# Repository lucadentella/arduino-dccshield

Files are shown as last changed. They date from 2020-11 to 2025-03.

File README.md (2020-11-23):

# DCCShield for Arduino

Optocoupled interface to connect Arduino to the DCC bus.

Available both as an Arduino shield and as a standalone board.

*Interfaccia optoisolata per collegare Arduino al bus DCC.*

*Disponibile sia come shield Arduino che come scheda autonoma.*

## Firmware

In the Arduino folder, a basic sketch is available to implement a DCC decoder as explained in the video.

*Nella cartella Arduino, è disponibile un semplice sketch per implementare un decoder DCC come illustrato nel video.*

## Documentation

 - [Tutorial in **English**](https://youtu.be/aA6cgGWZWBE) (Youtube)
 - [Tutorial in **Italiano**](https://youtu.be/_3cTWvrFvNA) (Youtube)

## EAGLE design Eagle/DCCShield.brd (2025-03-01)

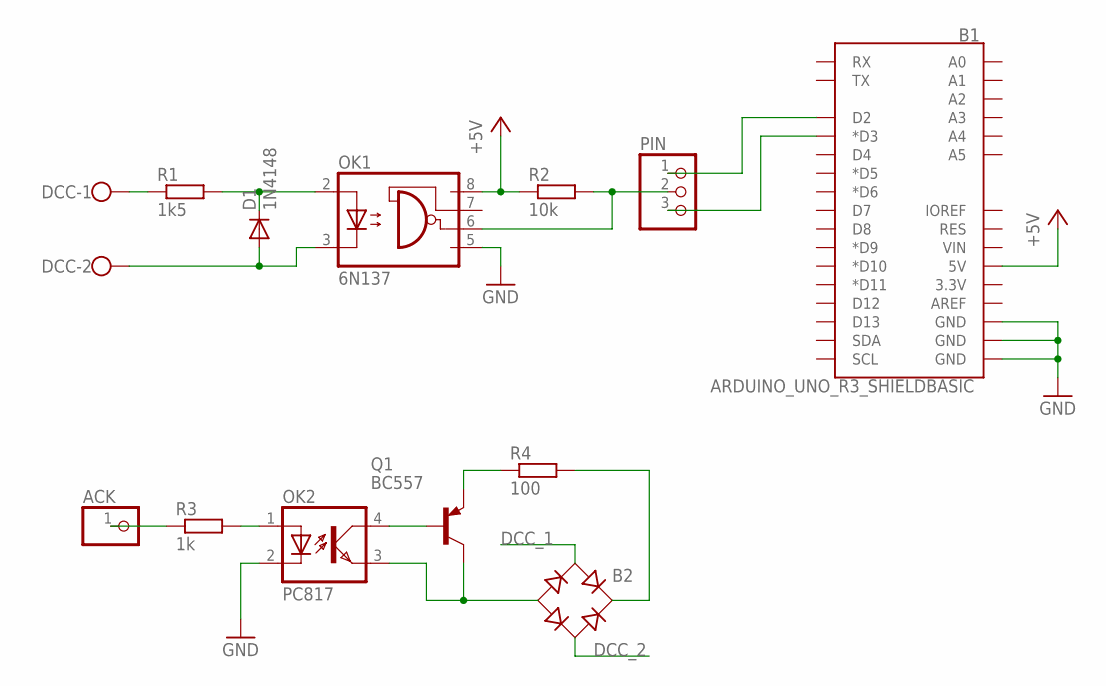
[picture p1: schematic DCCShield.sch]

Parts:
ACK: PINHD-1X1; 1X01
B1: ARDUINO_UNO_R3_SHIELDBASIC; UNO_R3_SHIELD
B2: RB1A
D1: 1N4148; DO35-10
DCC: W237-102
OK1: 6N137; DIL08
OK2: PC817; DIL04
PIN: PINHD-1X3; 1X03
Q1: BC557; TO92
R1: 1k5; 0207/10
R2: 10k; 0207/10
R3: 1k; 0207/10
R4: 100; 0207/10

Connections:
+5V: B1.5V, OK1.8 (VCC), R2.1
DCC_1: B2.AC1, DCC.1, R1.1
DCC_2: B2.AC2, D1.A, DCC.2, OK1.3 (C)
GND: B1.GND@0 (GND), B1.GND@1 (GND), B1.GND@2 (GND), OK1.5 (GND), OK2.2 (C)
unnamed: B2.-, OK2.3 (EMIT), Q1.3 (C)
unnamed: D1.C, OK1.2 (A), R1.2
unnamed: ACK.1, R3.1
unnamed: OK1.6 (VO), PIN.2, R2.2
unnamed: B1.D2, PIN.1
unnamed: B1.D3 (*D3), PIN.3
unnamed: OK2.1 (A), R3.2
unnamed: OK2.4 (COL), Q1.2 (B)
unnamed: Q1.1 (E), R4.1
unnamed: B2.+, R4.2

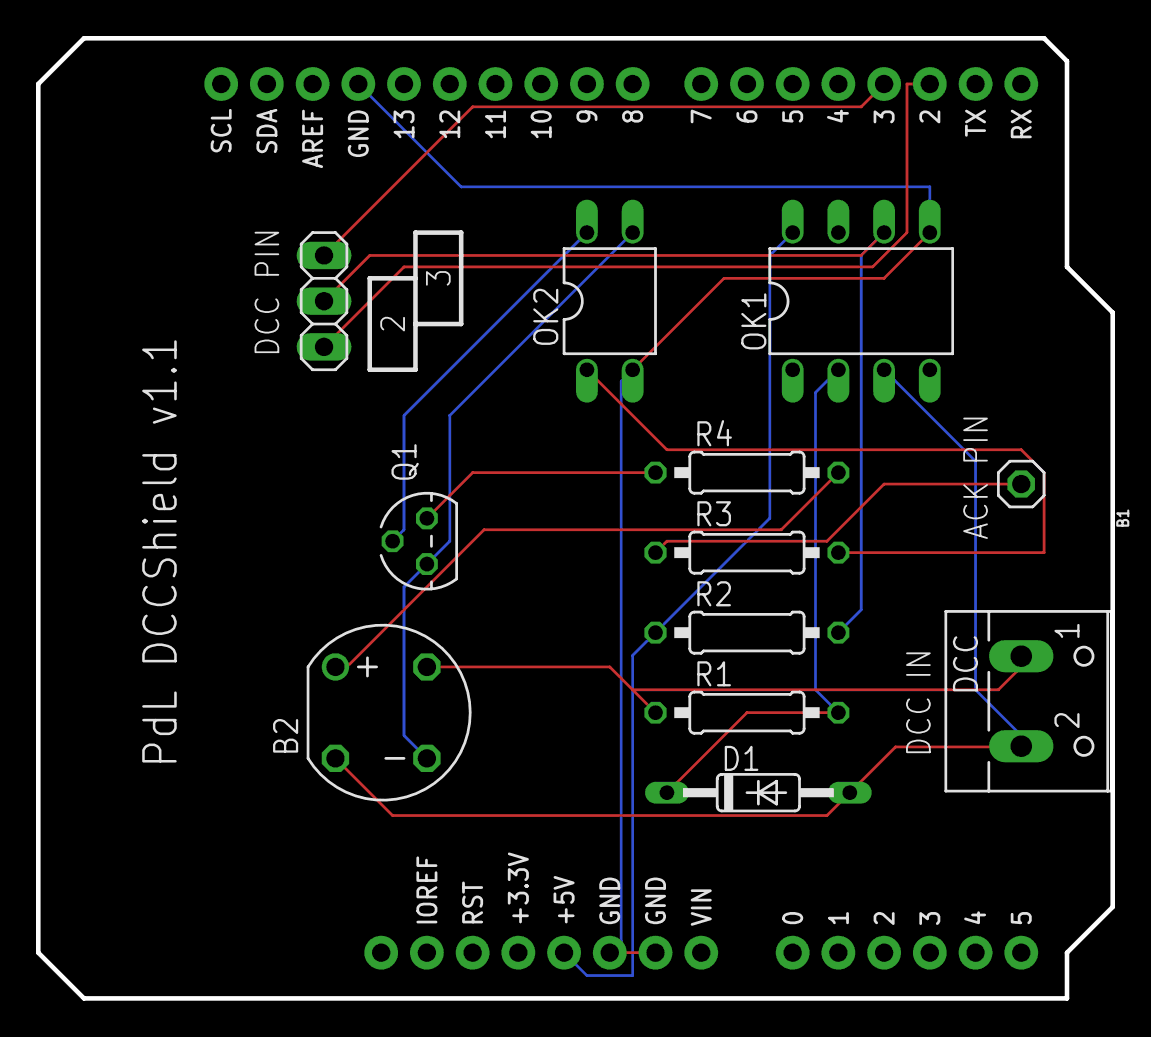
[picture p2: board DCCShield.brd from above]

Board: 2 copper layers, 59.7 x 53.3 mm, 13 parts (0 on the bottom side), 14 nets.

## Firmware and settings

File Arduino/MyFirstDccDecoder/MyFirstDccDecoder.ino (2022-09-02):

#include <NmraDcc.h>

#define DCC_PIN 2
#define ACK_PIN 3
#define RED_LED 4
#define GREEN_LED 5

#define DECODER_ADDR 4

NmraDcc Dcc;

void notifyDccAccTurnoutOutput(uint16_t Addr, uint8_t Direction, uint8_t OutputPower) {

  if(Addr == DECODER_ADDR) {
    if(Direction == 0) {
      digitalWrite(RED_LED, HIGH);
      digitalWrite(GREEN_LED, LOW);
    } else {
      digitalWrite(RED_LED, LOW);
      digitalWrite(GREEN_LED, HIGH);    
    }
  }
    
  Serial.print("Address: "); Serial.println(Addr);
  Serial.print("Direction: "); Serial.println(Direction);
  Serial.print("OutputPower: "); Serial.println(OutputPower);
  Serial.println("--------------------");
}

void notifyCVAck(void) {

  digitalWrite(ACK_PIN, HIGH);
  delay(10);  
  digitalWrite(ACK_PIN, LOW);
}

void setup() {

  Serial.begin(115200);
  pinMode(ACK_PIN, OUTPUT);
  pinMode(RED_LED, OUTPUT);
  pinMode(GREEN_LED, OUTPUT); 
  Dcc.pin(digitalPinToInterrupt(DCC_PIN), DCC_PIN, false);
  Dcc.init(MAN_ID_DIY, 1, FLAGS_DCC_ACCESSORY_DECODER | FLAGS_OUTPUT_ADDRESS_MODE, 0);
  Dcc.setCV(CV_ACCESSORY_DECODER_ADDRESS_LSB, DECODER_ADDR & 0xFF);
  Dcc.setCV(CV_ACCESSORY_DECODER_ADDRESS_MSB, DECODER_ADDR >> 8);
}

void loop() {

  Dcc.process();
}

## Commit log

2020-11-23 Standalone interface added
    [DCCInterface.brd, DCCInterface.sch, DCCShield.brd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]
2021-05-13 Create Arduino build workflow
2025-03-01 Updated to ver 1.1
    [DCCShield.brd, DCCShield.sch]

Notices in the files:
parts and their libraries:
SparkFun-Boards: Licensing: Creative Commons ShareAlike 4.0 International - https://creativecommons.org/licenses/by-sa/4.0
